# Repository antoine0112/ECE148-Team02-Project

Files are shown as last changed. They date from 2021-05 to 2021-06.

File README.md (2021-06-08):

# ECE148-Team02-Project
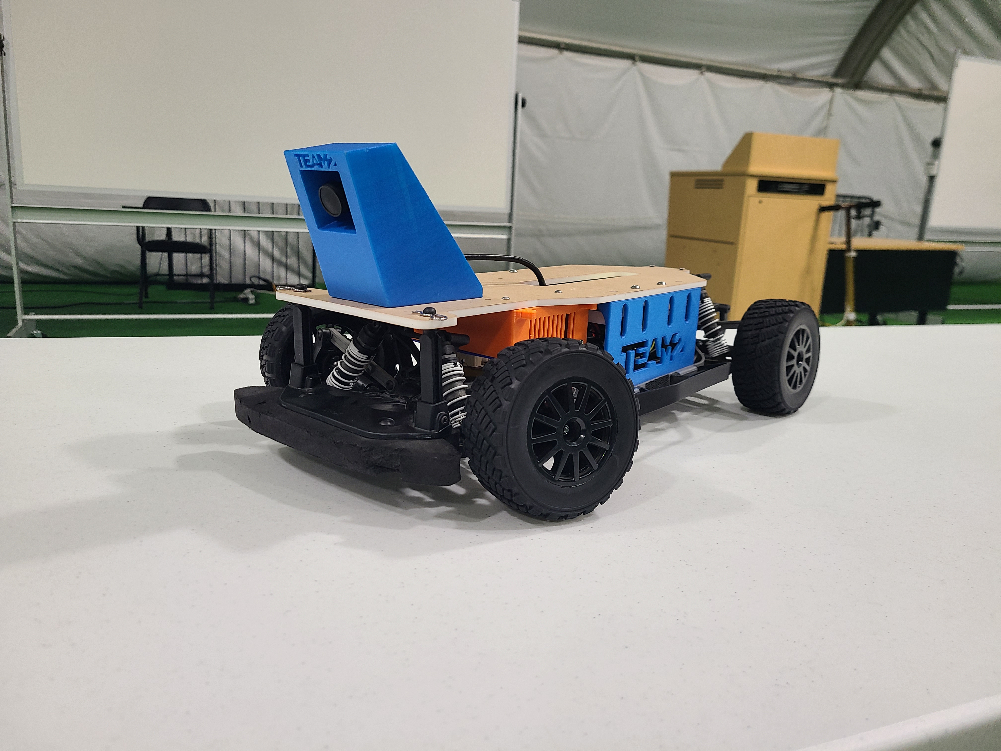
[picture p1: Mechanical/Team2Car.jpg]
ECE148-Team02-Car


As part of ECE/MAE148, Team02 developed an ESP32 vehicle control system, with robust emergency stop features and an expandable webserver-based remote control.
Based on the DonkeyCar's electrical framework, the use of an ESP32 replaces the PCA9685 motor driver, as well as the remote Estop relay board. 

Details about the project can be found here: https://guitar.ucsd.edu/maeece148/index.php/2021SpringTeam2

Usage of the ESP32 provides multiple benefits:

- Using a standard USB cable to both power and communicate with serial between the Jetson and ESP32 simplifies wiring. 
- Wifi access point capabilities of the ESP32 enable long range, multi-device access.
- The ESP32's dual core allows for an always-on webserver on one core, with a watchdog monitored motor driver on the other, providing high-speed and robust processing.

Code for flashing the ESP32 can be found under nodeMCU-32S-DualCore/src/main.cpp .
We also recommend using Platform.io for developing on the ESP32, which helps in flashing the webserver Javascript code to the ESP32. 
The Javascript code is found under nodeMCU-32S-DualCore/data/ . 
Configuring a new ESP32 device is simple, just change the Wifi SSID and password parameters.

An example for reading and sending JSON strings through serial can be found under scripts. 
These existing scripts subscribe to ROS /throttle and /steering topics, packaging and sending them over Serial.

This repository is set up to be easily git-cloned as a ROS package. 
Simply create a new package and clone the contents of this repository into the package folder, making sure to edit the package name as necessary.

Also included under mechanical/ are CAD files for camera mounts, base plates, and protective walls which we used on our car. Feel free to alter and use these files.

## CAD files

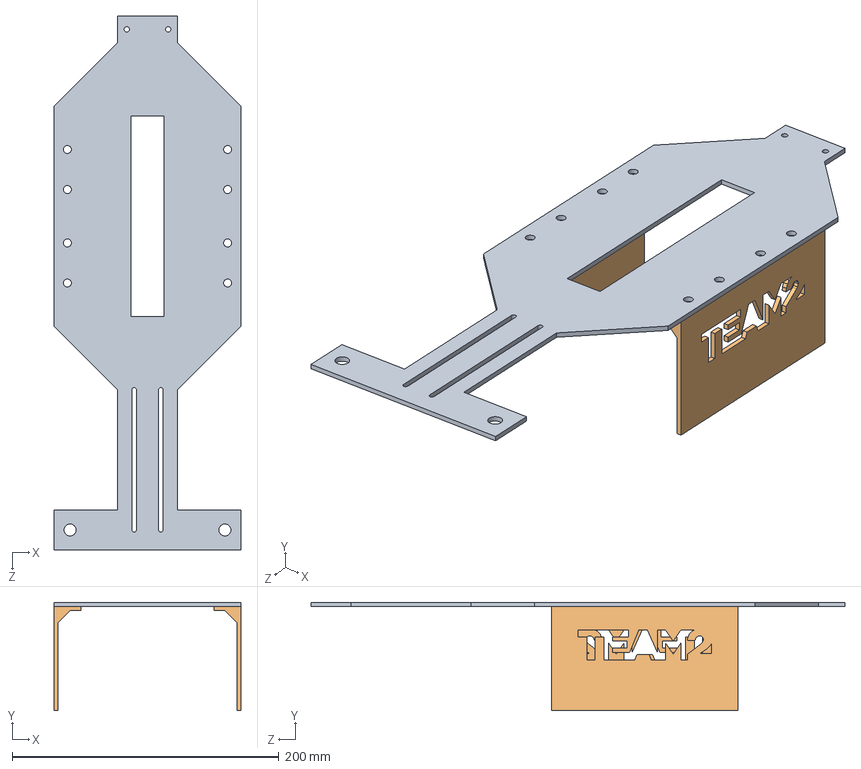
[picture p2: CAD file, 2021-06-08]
Mechanical/Base Assembly.SLDASM
140.0 x 81.0 x 400.0 mm
Base
Support x 2

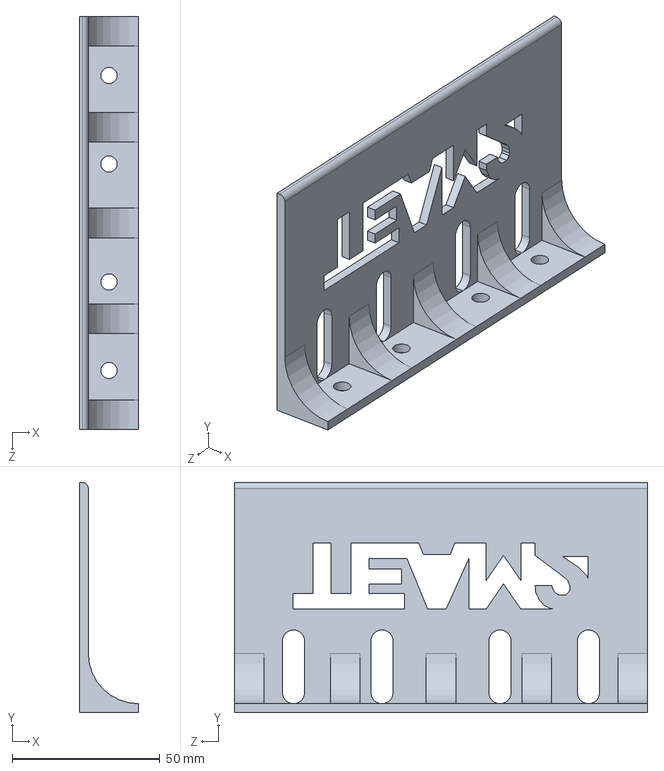
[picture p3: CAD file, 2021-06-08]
Mechanical/Support.SLDPRT
20.0 x 78.0 x 140.0 mm

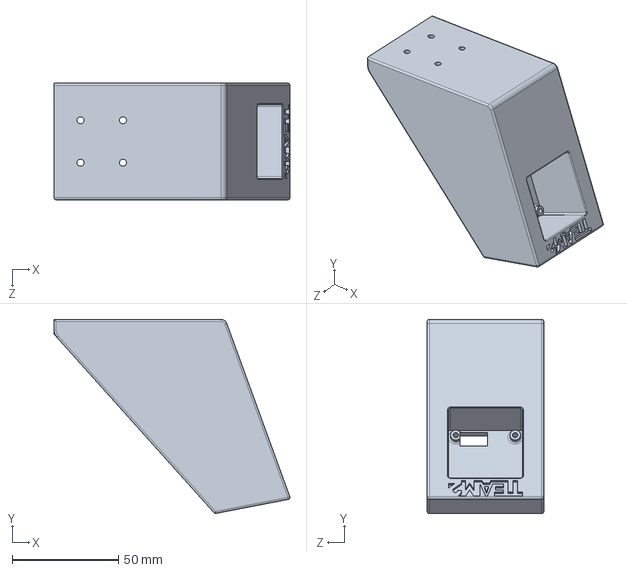
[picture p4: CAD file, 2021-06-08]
Mechanical/Camera Mount V5.SLDPRT
111.2 x 91.6 x 55.0 mm

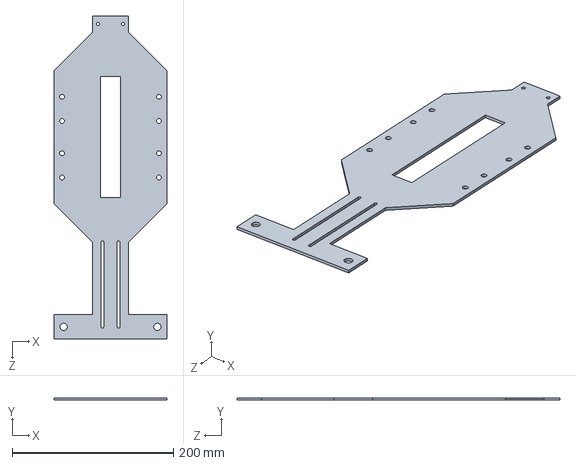
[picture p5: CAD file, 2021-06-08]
Mechanical/Base.SLDPRT
140.0 x 3.00 x 400.0 mm

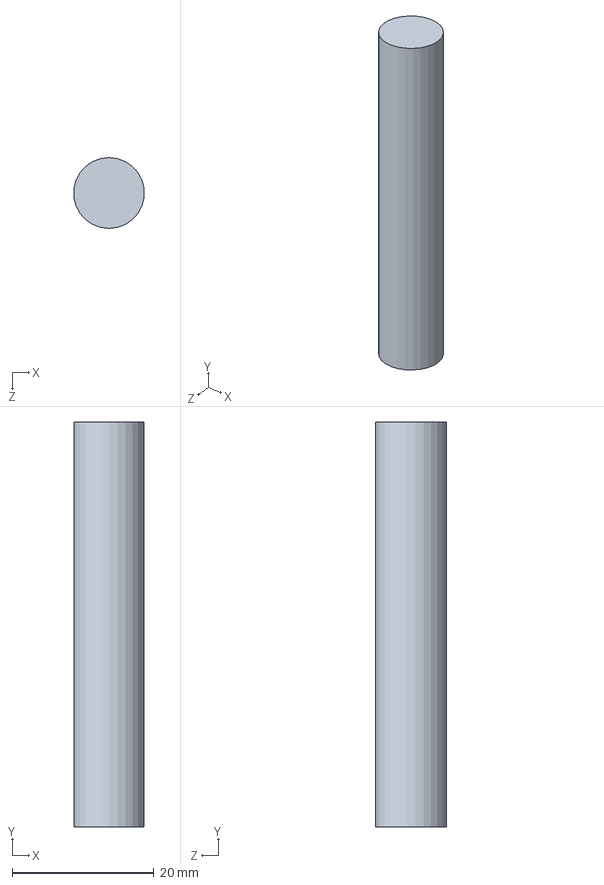
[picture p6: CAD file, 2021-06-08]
Mechanical/tempChassisPost.SLDPRT
9.93 x 57.1 x 10.0 mm

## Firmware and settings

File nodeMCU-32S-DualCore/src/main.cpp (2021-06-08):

// Dependancies
#include <Arduino.h>
#include <SPIFFS.h>
#include <WiFi.h>
#include <ESPAsyncWebServer.h>
#include <ArduinoJson.h>
#include <math.h>
#include <esp_int_wdt.h>
#include <esp_task_wdt.h>
#include <ESP32Servo.h>

// Macros
#define SERVO_PIN 0
#define ESC_PIN 4
#define RED_PIN 15
#define BLUE_PIN 16
#define HTTP_PORT 80
#define TIMEOUT 500
#define WDT_TIMEOUT 3
#define STEERING_CHN 3
#define IDLE_THROT 1500
#define BRAKE_THROT 1000
#define MAX_THROT 2000
#define LEFT_STEER 84
#define MID_STEER 116
#define RIGHT_STEER 148
#define QUEUE_SIZE 10

// WiFi Credentials
const char *WIFI_SSID = "ESP32Test";
const char *WIFI_PASS = "jetsonucsd";

// Button Component
struct Button {
    uint8_t pin;
    bool    on;
    void update() {digitalWrite(pin, on ? HIGH : LOW);}
};

// Instances
Button red_Button = {RED_PIN, false };
Button blue_Button = {BLUE_PIN, false };
AsyncWebServer server(HTTP_PORT);
AsyncWebSocket ws("/ws");
Servo pwmThrottle;
TaskHandle_t server_Handle;
TaskHandle_t pwm_Handle;
QueueHandle_t server2PWM_QueueHandle;
QueueHandle_t server2Status_QueueHandle;

// FiLL In Buttons For New Users Using Current Values
String processor(const String &var) {
    String buttons = "";
    if(var == "BUTTONS"){
        String red_state = red_Button.on?"on":"off",
               blue_state = blue_Button.on?"on":"off";
        buttons += "<button id='red_Button' class="+red_state+"></button>";
        buttons += "<button id='blue_Button' class="+blue_state+"></button>";
    }
    return buttons;
}

// Locate HTML Page
void onRootRequest(AsyncWebServerRequest *request) {
    request->send(SPIFFS, "/index.html", "text/html", false, processor);
}

// WebSocket Events
void onEvent(AsyncWebSocket       *server,
             AsyncWebSocketClient *client,
             AwsEventType          type,  
             void                 *arg,   
             uint8_t              *data,  
             size_t                len) { 

    // Incoming Message
    if(type == WS_EVT_DATA) {
        AwsFrameInfo *info = (AwsFrameInfo*)arg;
        if(info->final && info->index == 0 && info->len == len && info->opcode == WS_TEXT) {
            // Deseralize Message
            const uint8_t size = JSON_OBJECT_SIZE(2);
            StaticJsonDocument<size> json;
            DeserializationError err = deserializeJson(json, data);
            if(err){ return;}
            
            // Update Red Button
            if(strcmp(json["Button"], "red_Button") == 0) {
                red_Button.on = !red_Button.on;
                json["status"] = red_Button.on? "on": "off";
                xQueueSend(server2PWM_QueueHandle, &(red_Button.on), 0);
            } 
            // Update blue Button
            else if(strcmp(json["Button"], "blue_Button") == 0) {
                blue_Button.on = !blue_Button.on;
                json["status"] = blue_Button.on? "on": "off";
            }
               
            // Sync Devices
            char syncData[40];
            ws.textAll(syncData, serializeJson(json, syncData));
        }
    }
}

// Server Initialization
void serverSetup() {
    // Define Pin Behavior
    pinMode(red_Button.pin, OUTPUT);
    pinMode(blue_Button.pin, OUTPUT);
    
    // Activate Serial Monitor 
    delay(500);
  
    // Start SPIFFS
    SPIFFS.begin();
    
    // Create Soft Access Point
    WiFi.softAP(WIFI_SSID, WIFI_PASS);
    
    // Start Web Socket
    ws.onEvent(onEvent);
    server.addHandler(&ws);
    
    // Launch Web Server
    server.on("/", onRootRequest);
    server.serveStatic("/", SPIFFS, "/");
    server.begin();
    Serial.println("\nServer Ready to go");
}

// Server Loop
void serverTasks(void* param) {
    Serial.print("serverTasks running on core ");
    Serial.println(xPortGetCoreID());
    int status = 0;
    int i = 0;
    while (true)
    {   // Update Buttons
        if (xQueueReceive(server2Status_QueueHandle, &i, 0) == pdTRUE) {
            const uint8_t size = JSON_OBJECT_SIZE(2);
            StaticJsonDocument<size> json;
            json["Button"] = "None";
            json["status"] = i;
            char syncData[40];
            ws.textAll(syncData, serializeJson(json, syncData));
        }


        red_Button.update();
        blue_Button.update();

        // Close Lingering WebSockets
        if(millis()%1000 == 0){ ws.cleanupClients();}
        delay(400);
    }
}

// PWM Initialization
void pwmSetup() {
    // Initialize throttle
    pinMode(ESC_PIN, OUTPUT);
    pwmThrottle.attach(ESC_PIN);
    pwmThrottle.writeMicroseconds(IDLE_THROT);
    
    // Initialize steering
    pinMode(SERVO_PIN, OUTPUT);
    ledcSetup(STEERING_CHN, 300, 8);
    ledcAttachPin(SERVO_PIN, STEERING_CHN);
    ledcWrite(STEERING_CHN, MID_STEER);
    
    //enable panic so ESP32 restarts
    esp_task_wdt_init(WDT_TIMEOUT, true); 
    
    // Delay to calibrate ESC
    delay(7000);
    Serial.println("PWM Ready to go");
}

// PWM Loop
void pwmTasks(void* param) {
    bool killed;
    Serial.print("pwmTasks running on core ");
    Serial.println(xPortGetCoreID());
    unsigned long begin = millis();
    unsigned long end = millis();
    esp_task_wdt_add(NULL);
    bool i = false;
    while(true)
    {    
        Serial.print("red button: ");
        //Serial.println(red_Button.on);
        delay(100);
        // Serial Check
    
        if (!server2PWM_QueueHandle) {
            Serial.println("QUEUE NOT SET");
        }
        if (xQueueReceive(server2PWM_QueueHandle, &i, 0) == pdTRUE) {
            Serial.print("BUTTON == ");
            Serial.println(i);
            if (i) {
                killed = true;
            } else {
                killed = false;
            }
            Serial.print("killed == ");
            Serial.println(killed);
        }
        while(!Serial.available() && (end-begin) < 200) {end = millis();}
        if(end-begin >= 200) {
            Serial.println("Enterning backup routine");
            while(1) {
                pwmThrottle.writeMicroseconds(IDLE_THROT);
                ledcWrite(STEERING_CHN, MID_STEER);
                delay(100);
            }
        }
        
        // Get Message
        String payload;
        if(Serial.available()) {
            begin = millis();
            end = millis();
            esp_task_wdt_reset();
            payload = Serial.readStringUntil( '\n' );
        }
  
        // Deserialize Message
        const uint8_t size = JSON_OBJECT_SIZE(1000);
        StaticJsonDocument<size> doc;
        DeserializationError error = deserializeJson(doc, payload);
        if (error) {    
        } else {
            // Calculate Steering and Throttle
            float normalized_throttle = doc["throttle"];
            float normalized_steering = doc["steering"];
            int steering_pwm = !i? MID_STEER+int(normalized_steering*int((RIGHT_STEER-LEFT_STEER)/2)): MID_STEER;
            int throttle_pwm = !i? IDLE_THROT+int(normalized_throttle*500): IDLE_THROT;
            ledcWrite(STEERING_CHN, steering_pwm);
            pwmThrottle.writeMicroseconds(throttle_pwm);
            Serial.print("steering_pwm=");
            Serial.print(steering_pwm);
            Serial.print(" throttle_pwm=");
            Serial.println(throttle_pwm);
        };
    }
}

// Set Up
void setup()
{   // Start Server
    
    // Start PWM
    
    // Create Server to PWM Queue
    Serial.begin(115200);
    Serial.print("setup running on core ");
    Serial.println(xPortGetCoreID());
    server2PWM_QueueHandle = xQueueCreate(QUEUE_SIZE, sizeof(bool));
    server2Status_QueueHandle = xQueueCreate(QUEUE_SIZE, sizeof(int));
    if (!server2PWM_QueueHandle) {
        Serial.println("QUEUE NOT SET");
    }

    serverSetup();
    pwmSetup();
    xTaskCreatePinnedToCore(serverTasks, "ServerTasks", 10000, NULL, 2, &server_Handle, 0);
    delay(500); 
    xTaskCreatePinnedToCore(pwmTasks, "pwmTasks", 10000, NULL, 1, &pwm_Handle, 1);
    delay(500);
}

// Main Loop
void loop() {}

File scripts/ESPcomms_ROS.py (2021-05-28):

#!/usr/bin/env python
import rospy
from std_msgs.msg import Float32
import time
import json
import serial
from serial import SerialException
from pprint import pprint
import random

# ROS node and topic handles
NODE_NAME = 'ESPcomms_ROS'
STEERING_TOPIC_NAME = '/steering'
THROTTLE_TOPIC_NAME = '/throttle'
serialPort = "/dev/ttyUSB0"
serialBaud = 115200
# serialBaud = 9600

# Serial settings
ser  = serial.Serial(serialPort, baudrate= serialBaud, 
        timeout=0.5, 
        parity=serial.PARITY_NONE, 
        bytesize=serial.EIGHTBITS, 
        stopbits=serial.STOPBITS_ONE
    )

# Global storage for steering and throttle values
normalized_steering = 0.0
normalized_throttle = 0.0  




# steering topic callback
def callbackSteering(steerData):
    global normalized_steering
    normalized_steering = round(steerData.data,3)
    # print("normalized_steering", normalized_steering, "steerdata",steerData.data)
    # sendJSON()
    
# throttle topic callback
def callbackThrottle(throttleData):
    global normalized_throttle
    normalized_throttle = round(throttleData.data,3)
    # sendJSON()

# creates and returns a JSON filled with throttle, steering, and heartbeat data
def fillJSON():
    # print("normalized_throttle", normalized_throttle, "normalized_steering", normalized_steering)
    data = {}
    data["throttle"] = normalized_throttle
    data["steering"] = normalized_steering
    # data["heartbeat"] = round(time.time(),0)
    data2=json.dumps(data)
    # print("data2",data2)
    return data2 

    # return json.dumps({'throttle': normalized_throttle, 'steering': normalized_steering,'heartbeat':round(time.time(),0)})



# triggered periodically, or with new throttle/steering, sends JSON overserial
def sendJSON():
    data = fillJSON()

    
    if ser.isOpen():
            print("sending JSON!")
            data = data + " \n"
            ser.write(data.encode("ascii"))
            
            # data = "testMsg\n"
            print("encodedJSON = ", data.encode("ascii"))
            # print(fillJSON().encode('ascii'))
            # print(fillJSON().encode('utf-8'))
            # ser.write(fillJSON().encode('utf-8'))
            # print("writtn", ser.write(data.encode('ascii')))
            print('done sending')
            # print("debug sent ", ser.read(8))
            # print('done reqding')
            # print(ser.readline().decode("ascii"))
            ser.flush()
            try:
                print("entered the try incoming")
                
                dt = ser.readline()
                # print("debug", dt)
                incoming = dt.decode("ascii")
                print ("decodedMsg = ",incoming)    #what supposed to happen
            except Exception as e:
                print ('err', e)
                pass
            
    else:
        print ("opening error")



def main():
    rospy.init_node(NODE_NAME, anonymous=False)
    rospy.Subscriber(STEERING_TOPIC_NAME, Float32, callbackSteering)
    rospy.Subscriber(THROTTLE_TOPIC_NAME, Float32, callbackThrottle)
    
      
    # send the heartbeat at 20Hz
    rate = rospy.Rate(10) # 20Hz
    print("entering while loop")
    
    while not rospy.is_shutdown():
        rate.sleep()
        sendJSON()

    ser.close()
    print("killing serial")

if __name__ == '__main__':
    main()
    

    

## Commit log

2021-05-28 Arduino Files
2021-05-28 arduino libs
2021-05-28 working esp32 files
2021-05-28 add new esp32 file
2021-06-04 Created ESC test code
2021-06-04 feat(throttle): merge jack's throttle control
2021-06-05 fix(pwm): correct float division
2021-06-08 CAD Files
    [Base Assembly.SLDASM, Base.SLDPRT, Camera Mount V5.SLDPRT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]
2021-06-08 moving files
    [Base Assembly.SLDASM, Base.SLDPRT, Camera Mount V5.SLDPRT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]
